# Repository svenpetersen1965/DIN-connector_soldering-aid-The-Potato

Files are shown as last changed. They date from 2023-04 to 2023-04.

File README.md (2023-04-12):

# DIN Connector Soldering-aid "The Potato"

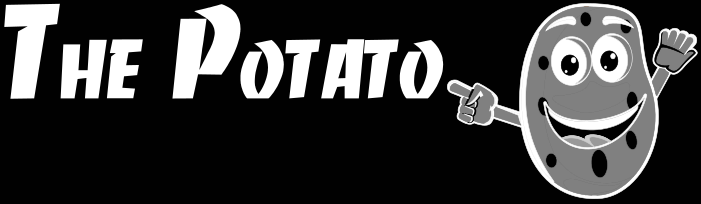
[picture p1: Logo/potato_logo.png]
The Potato


Helps with soldering DIN connectors. Holds the connector body and keeps the pins in place while soldering.

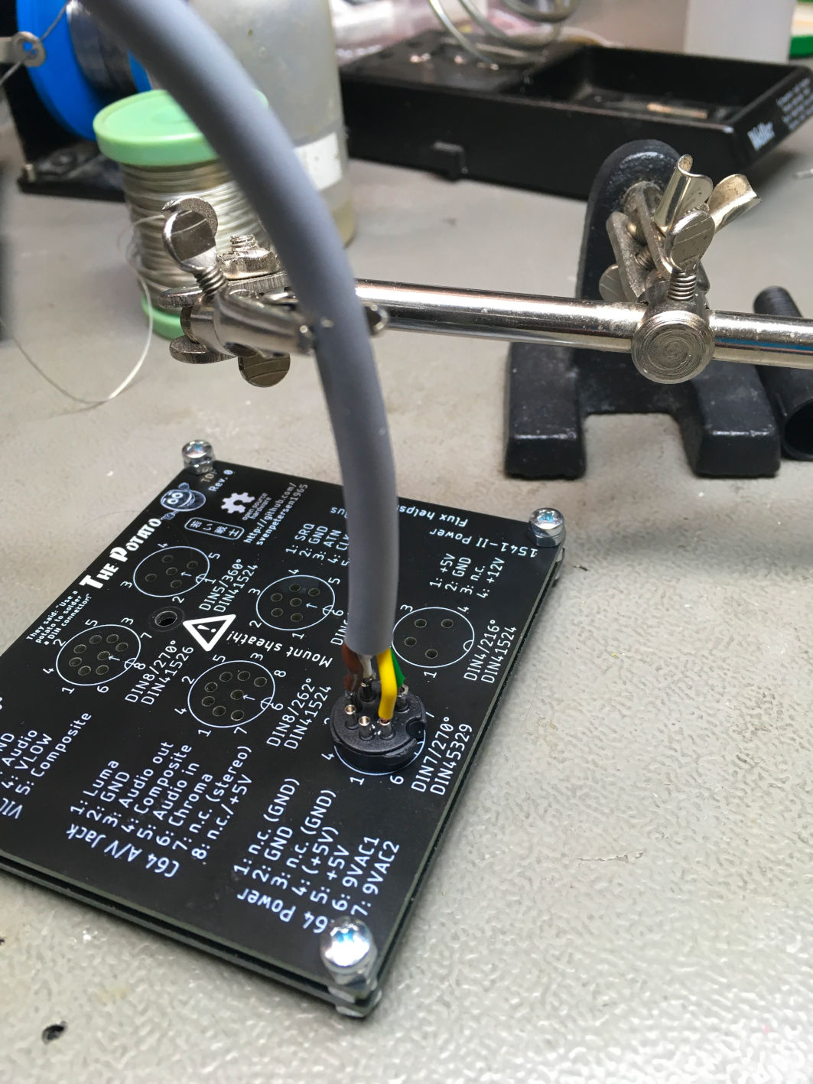
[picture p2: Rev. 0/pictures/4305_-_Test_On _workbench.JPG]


The logo is based on a file, obtained from https://freesvg.org/anthropomorphic-potato

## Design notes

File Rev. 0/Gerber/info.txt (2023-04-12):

      
       Board: The Potato
       Rev.:  0
  
       Files:
       ======
  
       All Gerber files are generated in extended gerber format (RS274X)
       *.TOP        : Film top copper
       *.BOT        :  -"- bottom copper
       *.STC        :  -"- top soldermask 
       *.STS        :  -"- bottom soldermask
       *.PLC        :  -"- silk screen top
       *.PLS        :  -"- silk screen Bottom
       *.DK         : Drills plated Through (Excellon)
       *.NDK        : Drills not plated Through (Excellon)
       *.OUT        : Board outline

       Board Size:
       ===========
       Length     :   83.0 mm
       Width      :   74.0 mm
       Thickness  :   1.6 mm
       Material   :   FR 4
       Copper     :   35 um
       Surface    :   HASL
       
       Remarks:
       ========

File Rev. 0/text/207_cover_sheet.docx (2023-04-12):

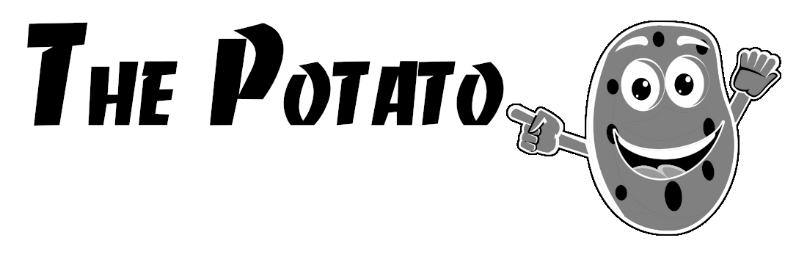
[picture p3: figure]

Project Documentation

DIN Connector Soldering-Aid: The Potato

Project number: 207

Revision: 0

Date: 26.03.2023

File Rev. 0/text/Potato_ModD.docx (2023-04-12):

DIN Connector Soldering-Aid – The Potato Rev. 0

Module Description

# Introduction

Soldering DIN connectors has never been real fun. Some people reported using a potato as soldering-aid. It is holding the connector in position and is cooling the pins while soldering to prevent the plastic body of the connector from melting.

But:

- Do you really want vegetables/food in your lab?
- Is it good to cool the pins of the connector, that is hard to solder, anyway?

It is also not clear, if there is an effect of the substances in a potato on the surface of the pins. Especially power connectors require a low impedance of the contact surfaces.

Pasi Lassila introduced me on Facebook to the idea of using a PCB as a DIN connector holder.

The goal of the development was to provide a solution, that holds the pins in place and that provides a variety of DIN connector configurations.

Those are:

- DIN8/270° (DIN 41526)
- DIN8/262° (aka “horseshoe”, DIN 41524)
- DIN7/270° (DIN 45329)
- DIN6/240° (DIN 45322)
- DIN5/360° (aka “dice”, DIN 41524)
- DIN4/216° (DIN41524)

The wide spread DIN5/180° fits on both DIN8 and the DIN7 footprint.

Further on, the PCB should serve as a cheat sheet for the pin numbers and some important pinouts in the retro computing world (especially Commodore computers).

According to the DIN standards, the pin diameter is 1.45mm. The drills on this board are 1.60mm. Thus, there is not a lot of friction when pulling out the connectors. An exception is the Belden/Hirschmann branded MAS 80 S (DIN8/262° horse shoe), which has a PIN diameter of 1.5mm. The PCB holds this connector with a medium high friction.

# Usage

- Stack two of the PCBs with the help of four screws (M3x12, e.g. DIN 7985) and 12 Nuts (M3, e.g. DIN 934)
- Put the stack with the inserted connector horizontally on the workbench while soldering
- Use a helping hand for holding the cable (covering the crocodile clamps with a shrinkable sleeve to prevent denting the cable)
- Solder one wire after the other

The soldering method is a recommendation. Different methods (“The Potato” clamped in different ways or on the workbench) were tried out. Horizontally on the workbench seems to be the best way, since the PCB can be rotated easily to access the solder joints from all directions.

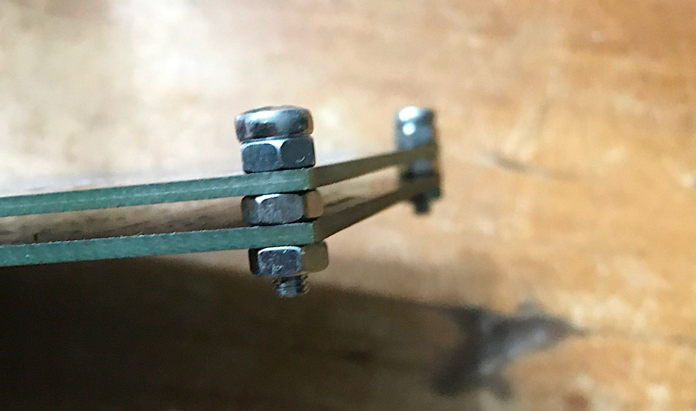
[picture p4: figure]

Figure 1: Method of stacking the PCBs with using nuts as spacers

# Test

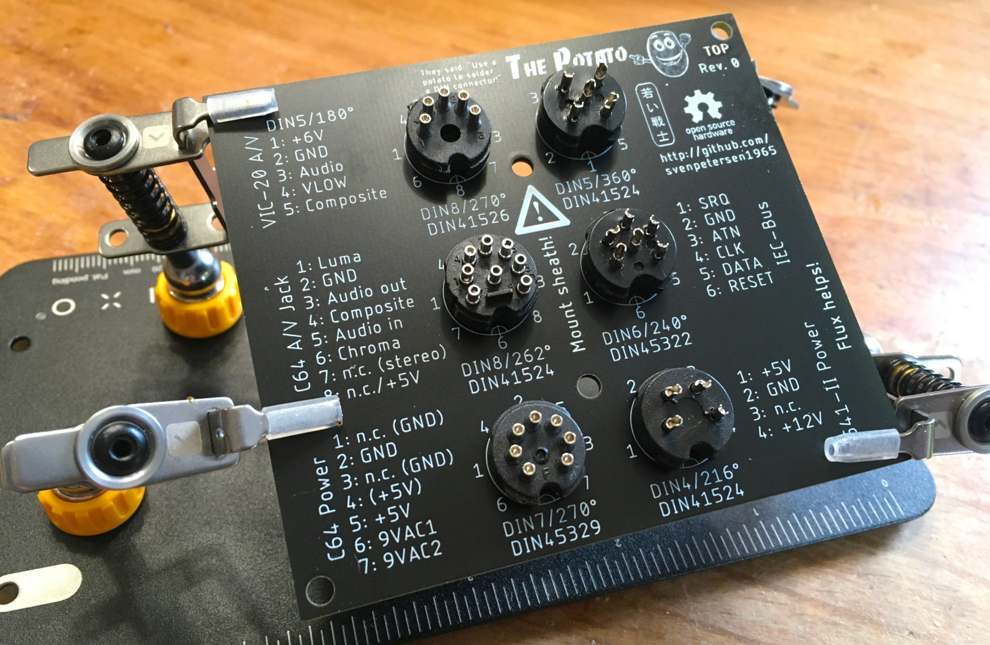
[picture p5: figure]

Figure 2: Test: Fitting all available connector types

The DIN8/270° was not available at the time of test.

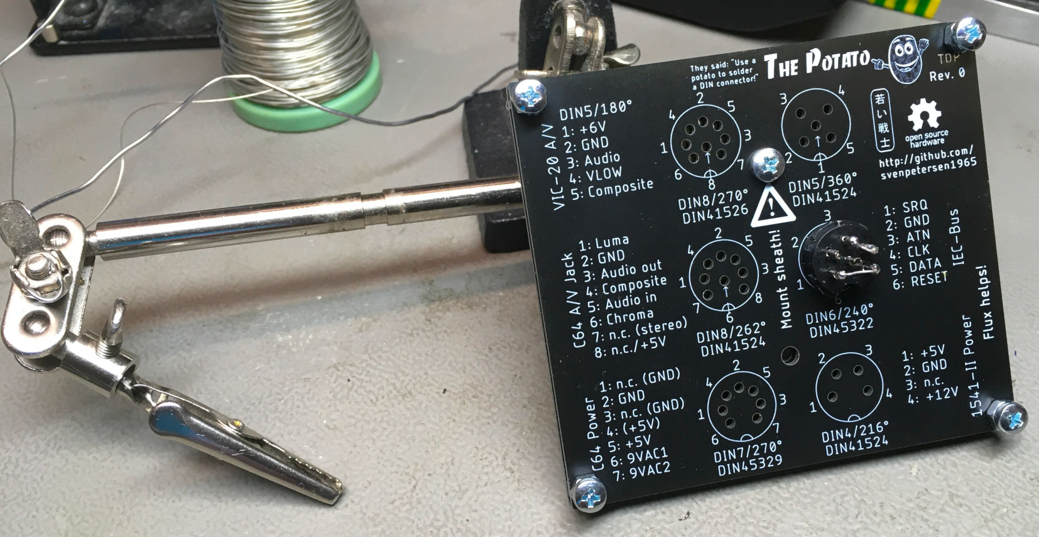
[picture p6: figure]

Figure 3: Soldering while the Potato is held with a helping hand


Figure 4: Test with the Potato on the workbench (best option)

# Dimensions

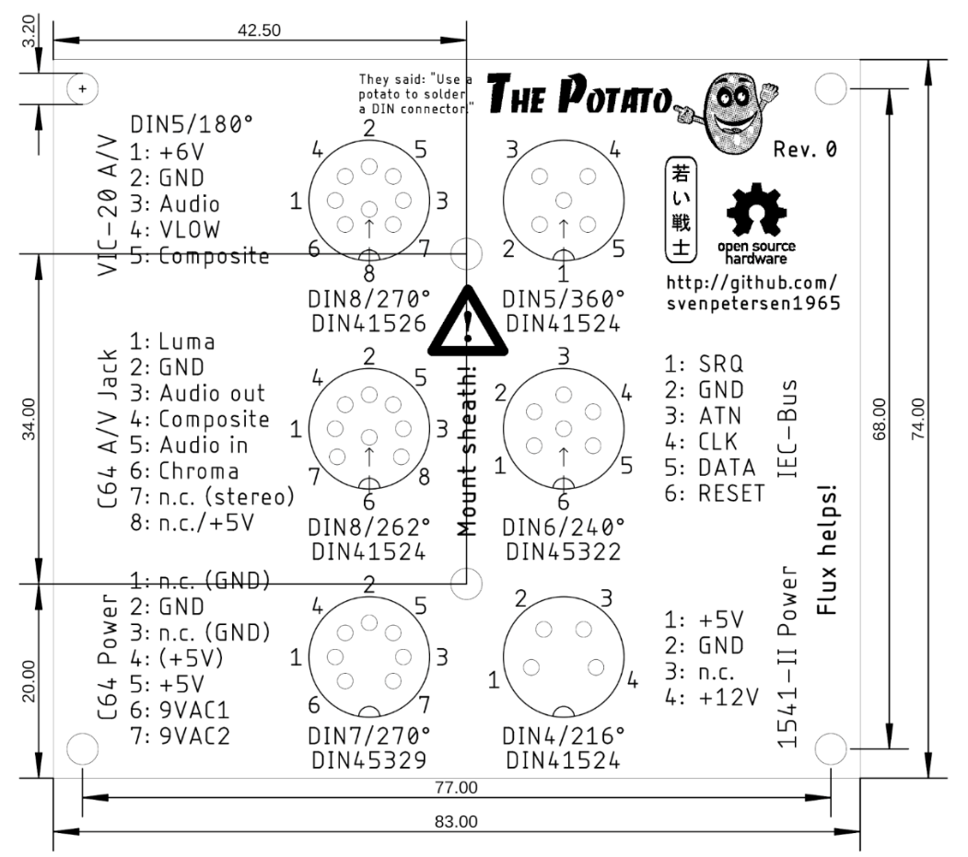
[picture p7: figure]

Figure 5: dimensions of the PCB

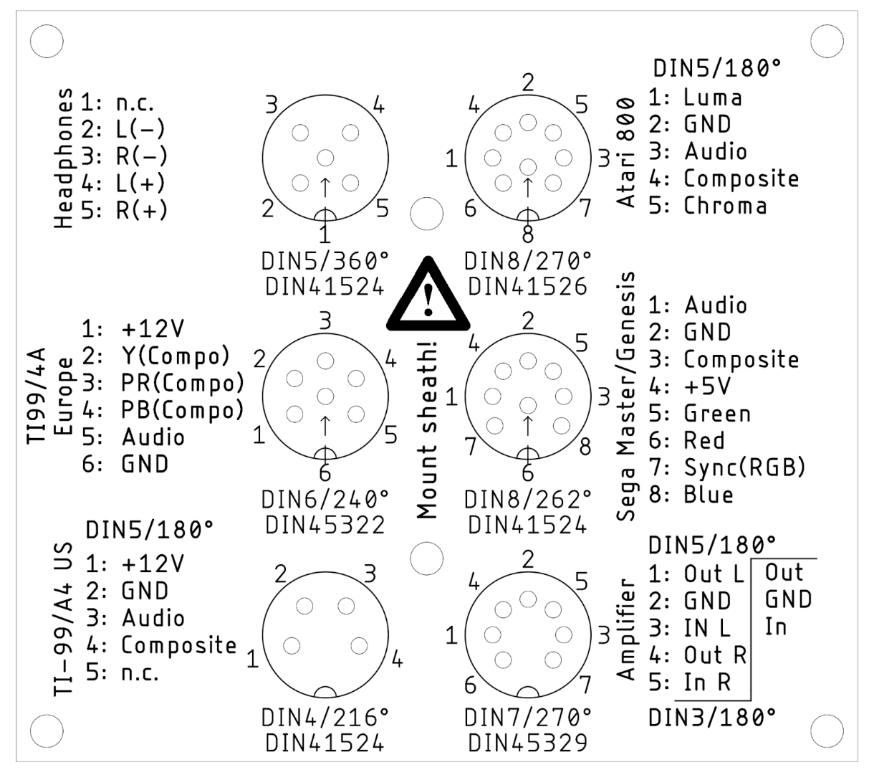
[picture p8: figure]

Figure 6: Bottom side of the PCB

# Disclaimer

I have carefully compared the different pinnings with the source, that I have found, but I cannot verify each source. Use on own risk.

Soldering DIN connectors is never fun and The Potato does not make it fun, but it helps holding the connector body while soldering. And it does it quite a bit nicer, than just using a helping hand. It holds the pins in place.

# Revision History

## Rev. 0

- Tested, all connectors could be inserted properly

Potato_ModD.docx 12.04.2023 23:48 Drafted by Sven Petersen Page 2 of 2 Doc.-No.: 207-6-01-00

Potato_ModD.docx 12.04.2023 23:48 Drafted by Sven Petersen Page 1 of 1 Doc.-No.: 000-6-00-00

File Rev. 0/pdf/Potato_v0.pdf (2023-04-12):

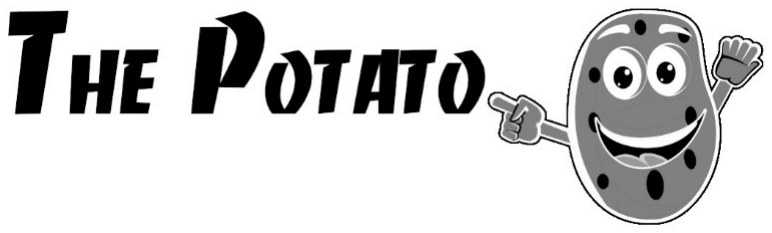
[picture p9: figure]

# Project Documentation

## DIN Connector Soldering-Aid: The Potato

## Project number: 207

## Revision: 0

## Date: 26.03.2023

Potato_ModD.docx | | 12.04.2023 23:48
Drafted by Sven Petersen | Page 1 of 5 | Doc.-No.: 207-6-01-00

### DIN Connector Soldering-Aid – The Potato Rev. 0

### Module Description

## Introduction

Soldering DIN connectors has never been real fun. Some people reported using a potato as soldering-aid. It is holding the connector in position and is cooling the pins while soldering to prevent the plastic body of the connector from melting.

But:

- Do you really want vegetables/food in your lab?
- Is it good to cool the pins of the connector, that is hard to solder, anyway?

It is also not clear, if there is an effect of the substances in a potato on the surface of the pins. Especially power connectors require a low impedance of the contact surfaces.

Pasi Lassila introduced me on Facebook to the idea of using a PCB as a DIN connector holder.

The goal of the development was to provide a solution, that holds the pins in place and that provides a variety of DIN connector configurations.

Those are:

- DIN8/270° (DIN 41526)
- DIN8/262° (aka <horseshoe=, DIN 41524)
- DIN7/270° (DIN 45329)
- DIN6/240° (DIN 45322)

### - DIN5/360° (aka <dice=, DIN 41524)

- DIN4/216° (DIN41524)

The wide spread DIN5/180° fits on both DIN8 and the DIN7 footprint.

Further on, the PCB should serve as a cheat sheet for the pin numbers and some important pinouts in the retro computing world (especially Commodore computers).

According to the DIN standards, the pin diameter is 1.45mm. The drills on this board are 1.60mm. Thus, there is not a lot of friction when pulling out the connectors. An exception is the Belden/Hirschmann branded MAS 80 S (DIN8/262° horse shoe), which has a PIN diameter of 1.5mm. The PCB holds this connector with a medium high friction.

## Usage

- Stack two of the PCBs with the help of four screws (M3x12, e.g. DIN 7985) and 12 Nuts (M3, e.g. DIN 934)
- Put the stack with the inserted connector horizontally on the workbench while soldering
- Use a helping hand for holding the cable (covering the crocodile clamps with a shrinkable sleeve to prevent denting the cable)
- Solder one wire after the other

The soldering method is a recommendation. Different methods (<The Potato= clamped in different ways or on the workbench) were tried out. Horizontally on the workbench seems to be the best way, since the PCB can be rotated easily to access the solder joints from all directions.

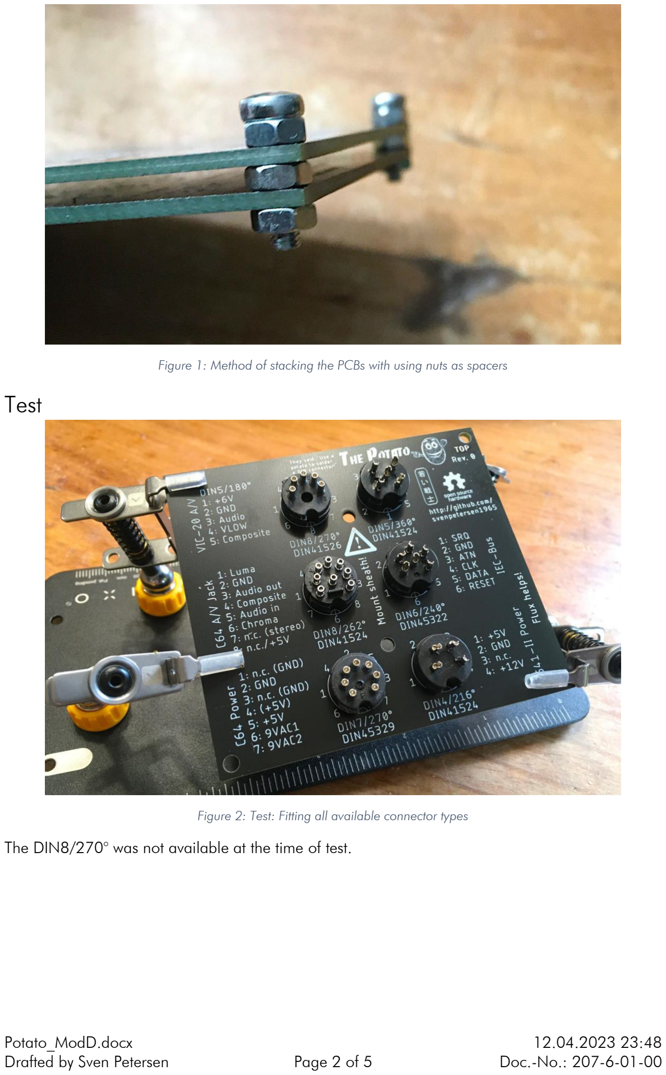
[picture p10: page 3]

Drafted by Sven Petersen | Page 2 of 5 | Doc.-No.: 207-6-01-00

Figure 1: Method of stacking the PCBs with using nuts as spacers

## Test

Figure 2: Test: Fitting all available connector types

The DIN8/270° was not available at the time of test.

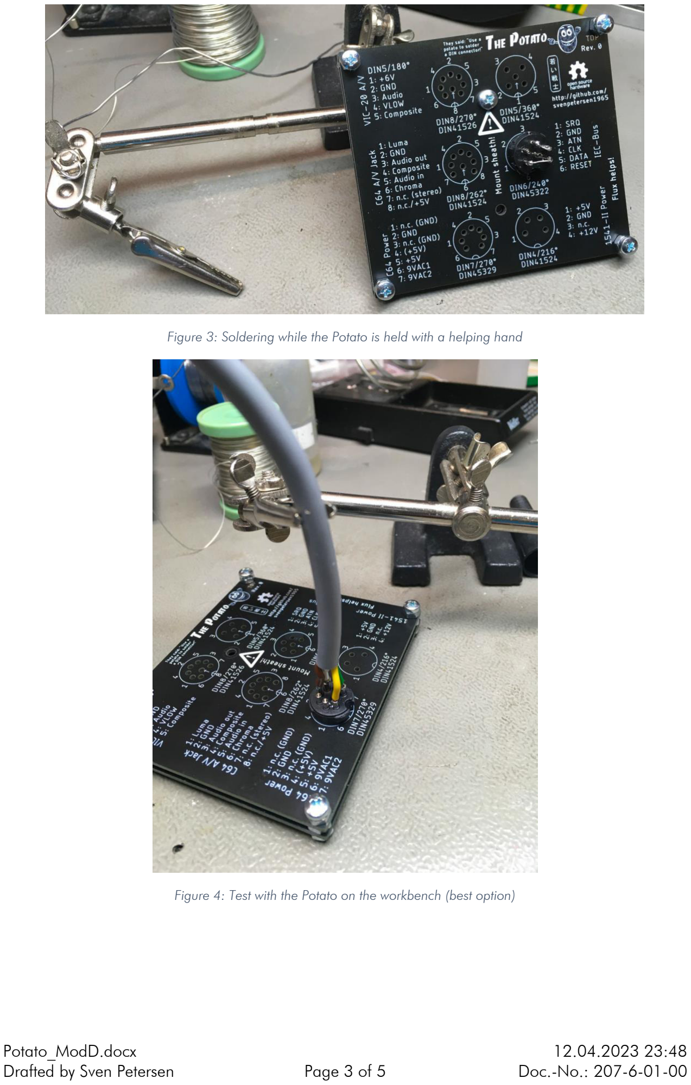
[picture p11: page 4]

Drafted by Sven Petersen | Page 3 of 5 | Doc.-No.: 207-6-01-00

Figure 3: Soldering while the Potato is held with a helping hand

Figure 4: Test with the Potato on the workbench (best option)

## Dimensions

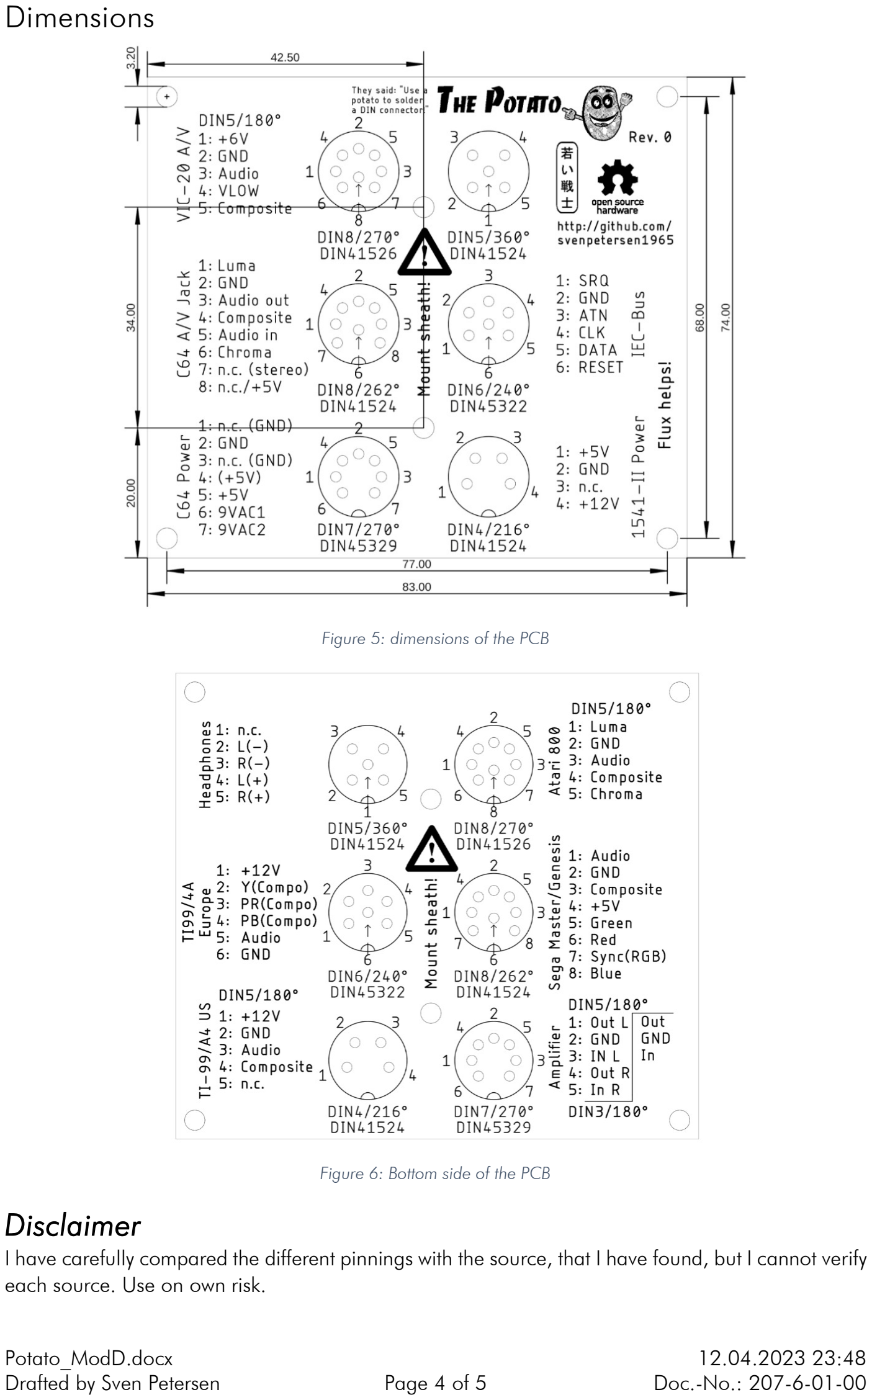
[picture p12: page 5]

Drafted by Sven Petersen | Page 4 of 5 | Doc.-No.: 207-6-01-00

Figure 5: dimensions of the PCB

Figure 6: Bottom side of the PCB

## Disclaimer

I have carefully compared the different pinnings with the source, that I have found, but I cannot verify each source. Use on own risk.

Drafted by Sven Petersen | Page 5 of 5 | Doc.-No.: 207-6-01-00

Soldering DIN connectors is never fun and The Potato does not make it fun, but it helps holding the connector body while soldering. And it does it quite a bit nicer, than just using a helping hand. It holds the pins in place.

## Revision History

### Rev. 0

- Tested, all connectors could be inserted properly

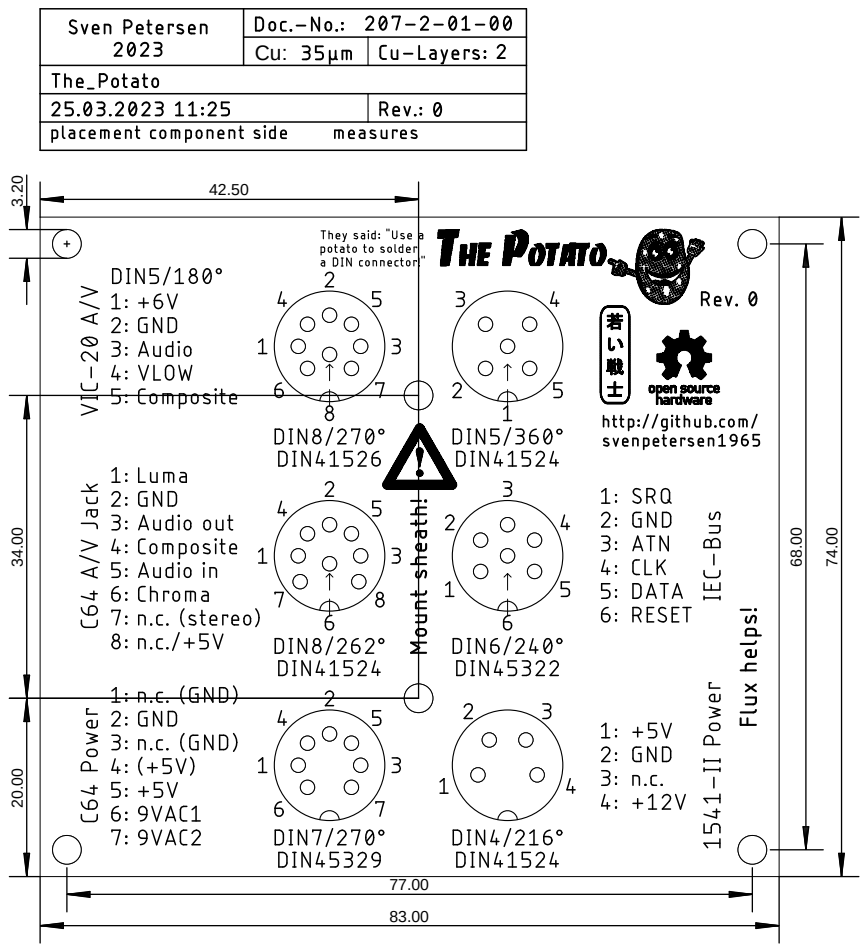
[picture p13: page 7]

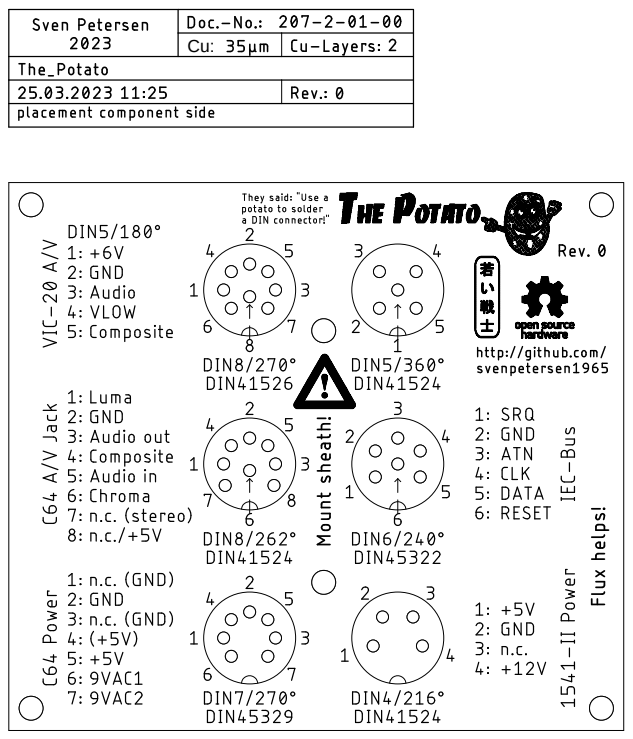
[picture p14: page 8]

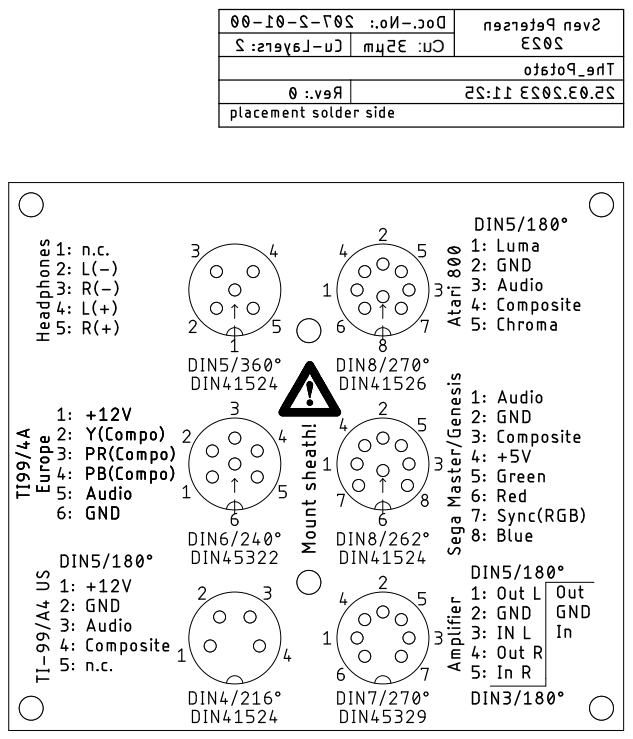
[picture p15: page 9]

Pos. Qty Value Footprint Ref.-No. Comment

1 2 207-2-01-00 2 Layer PCB Rev. 0 2 layer, Cu 35µ, HASL,74mm x 83mm, 1.6mm FR4

2 4 Screm M3x12 e.g. DIN 7985)
3 12 Nuts M3 e.g. DIN 934

## The Potato Rev. 0

## Bill of Material Rev. 0.0

Potato_BOM_v0_0.xlsx

Drafted by Sven Petersen Page 1 of 1

12.04.2023 23:55
Doc.No.: 207-5-01-00.0

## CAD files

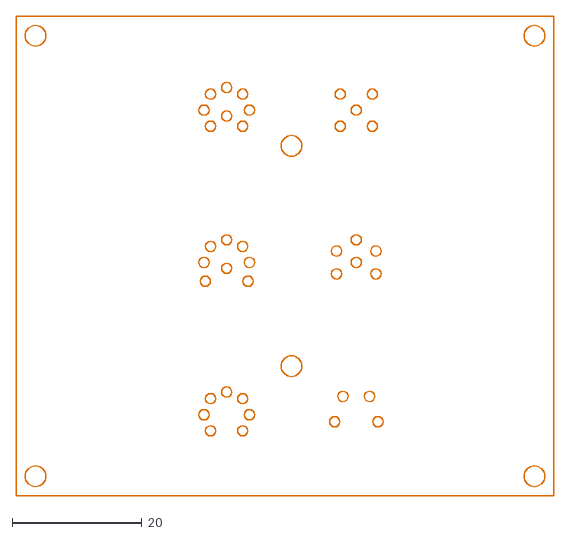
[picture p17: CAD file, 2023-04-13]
Rev. 0/dxf/The_Potato_outline.dxf
83.0 x 74.0

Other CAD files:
Rev. 0/dxf/The_Potato_bottomsilk.dxf
Rev. 0/dxf/The_Potato_topsilk.dxf

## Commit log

2023-04-13 A version without the document frame
    [The_Potato_noFrame.brd]
2023-04-13 A version for the lame pcb manufacturers
    It has no document frame.
